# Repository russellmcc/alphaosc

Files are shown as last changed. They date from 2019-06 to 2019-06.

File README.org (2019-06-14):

* What is this?

This repository includes the design files and code for a eurorack-format digital audio oscillator.

* What's special about this digital oscillator?

Unlike other digital oscillators, this has very low aliasing.  This is achieved by running at a very high sampling rate (megahertz range, depending on target output pitch).

Also, many unusual waveforms, such as "comb" waveforms or "variable pulse saw" waveforms can be output.

The basic design and the output waveforms available are inspired closely (but not precisely) by Roland's Alpha Juno line of synthesizers.

* Project structure

The four-layer circuit board was designed using [[http://kicad-pcb.org][kicad]] and is available in the ~pcb~ subfolder.

Code for the arduino (which is reponsible for interfacing with the A/D converter for CV signals) is in the ~arduino~ folder.

Code for the fpga is written in [[https://clash-lang.org][clash]] and available in the ~src~ folder.

Panel design files are in the ~panel~ folder.

Scripts to design the tuning table are in the ~design~ folder.

This is the code for a digital oscillator core of a hardware synthesizer NCO developed in clash and arduino.  The oscillator is inspired by the Alpha Juno line of synthesizers by Roland.

* Tips for building/running

Note that this is a fairly advanced build and should be considered a "build at your own risk" type affair.

verilog code for the FPGA can be built by running the ~build.sh~ script in the ~src~ folder.  To program the FPGA, you'll need to use Lattice's tools available on [[http://www.latticesemi.com][their website]].  Note that you'll also need to include the ~lattice_alpha.lpf~ which locates the pins.

To run the test suite for the FPGA code, run ~test.sh~ in the ~src~ folder.

Note that some fuses on the arduino need to be set, specifically the "clock out" fuse.  This can be programmed with the following one-liner:

#+begin_src bash
avrdude -c avrispmkii -p m328p -U lfuse:w:0xB7:m
#+end_src

* License

Distributed under the terms of the GPLv3 (available in COPYING).  By contributing to this project, you agree to license your contribution under those terms.

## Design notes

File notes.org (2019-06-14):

* Assembly errors (not going to fix)
 - Saw lsb is stuck high due to pins 9 and 10 being bridged - this is due to a bogus pad so would be hard to fix.
 - Ditto saw bit 5 (near LSB) is stuck low due to crazy assembly error
 - So, switched saw (which actually needs all bits) with SUB (which doesn't).
* Stuff left to do [0/1]
 - [ ] PROJECT DOCUMENTATION!

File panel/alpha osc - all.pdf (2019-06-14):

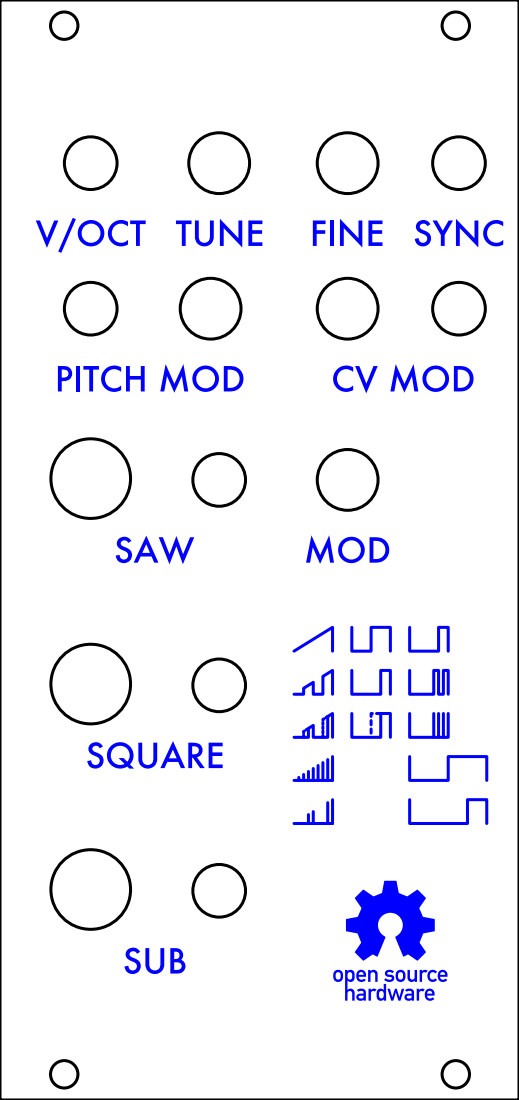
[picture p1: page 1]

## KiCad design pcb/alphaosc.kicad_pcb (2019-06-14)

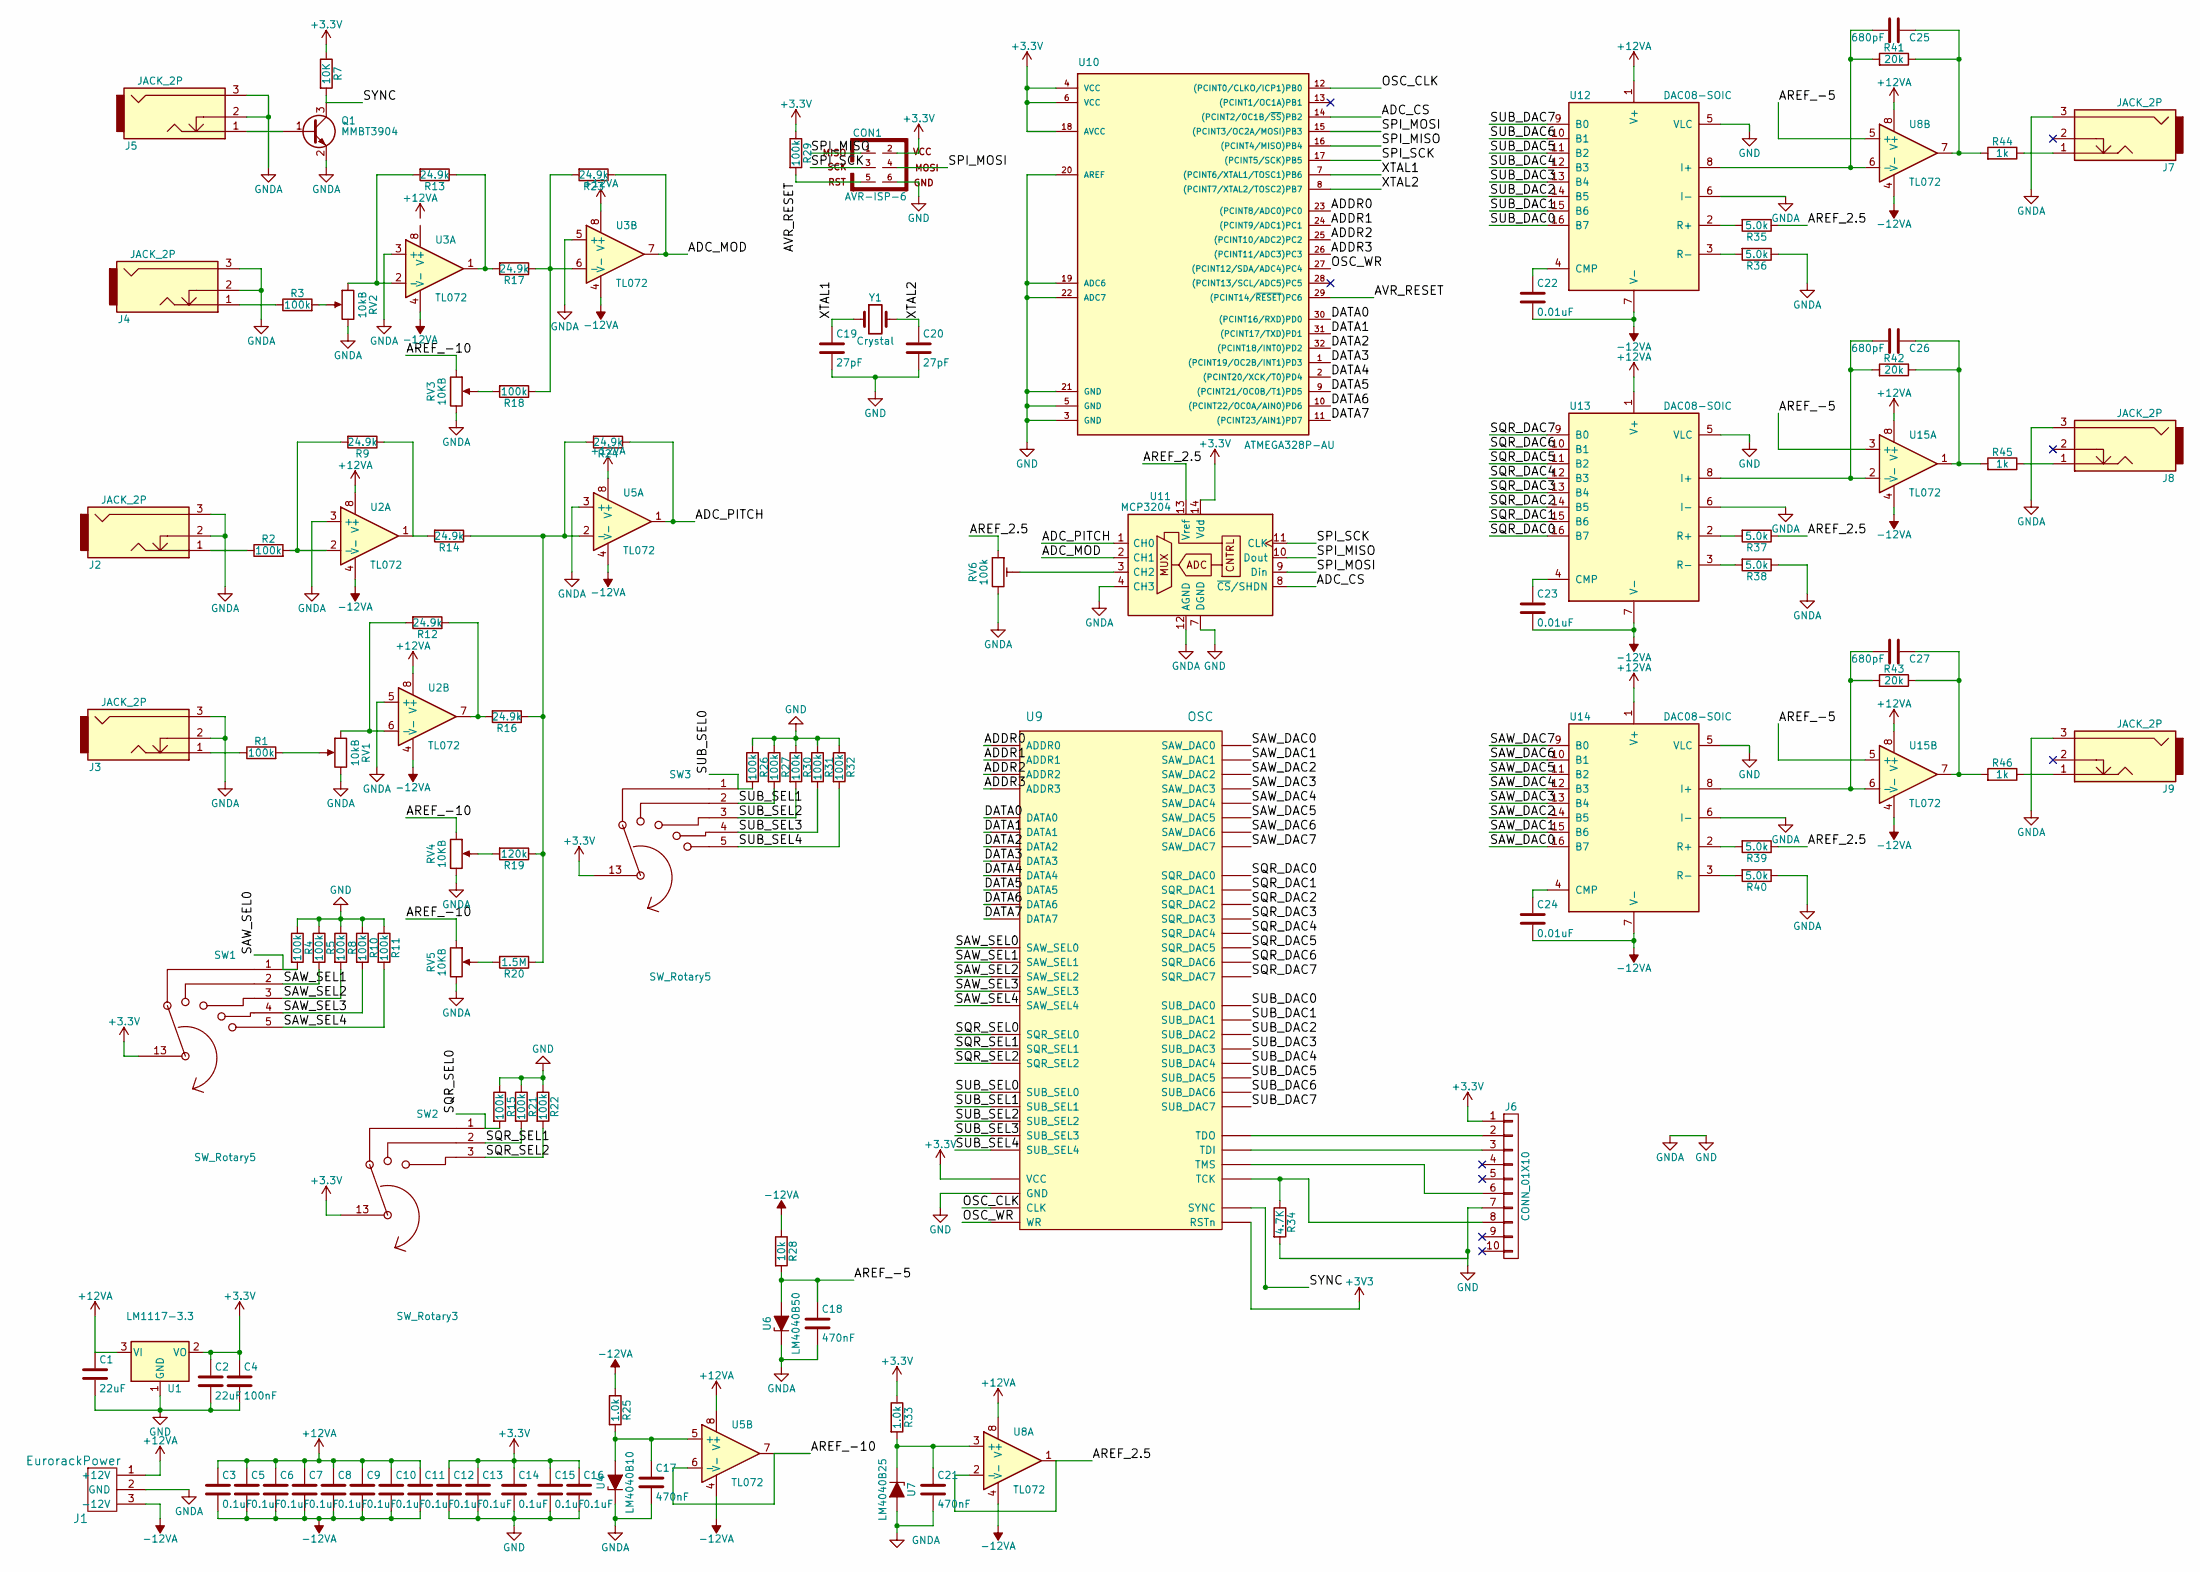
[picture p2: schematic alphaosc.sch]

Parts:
C1, C2: 22uF; C_0603
C3, C5, C6, C7, C8, C9, C10, C11, C12, C13, C14, C15, C16: 0.1uF; C_0603
C4: 100nF; C_0603
C17, C18, C21: 470nF; C_0603
C19, C20: 27pF; C_0603
C22, C23, C24: 0.01uF; C_0603
C25, C26, C27: 680pF; C_0603
CON1: AVR-ISP-6; Pin_Header_Straight_2x03_Pitch2.54mm
J1: EurorackPower; EurorackPower10
J2, J3, J4, J5, J7, J8, J9: JACK_2P; THONKICONN
J6: CONN_01X10; Pin_Header_Straight_1x10_Pitch2.54mm
Q1: MMBT3904; SOT-23
R1, R2, R3, R4, R5, R8, R10, R11, R15, R18, R21, R22, R26, R27, R29, R30, R31, R32: 100k; R_0603
R7: 10K; R_0603
R9, R12, R13, R14, R16, R17, R23, R24: 24.9k; R_0603
R19: 120k; R_0603
R20: 1.5M; R_0603
R25, R33: 1.0k; R_0603
R28: 10k; R_0603
R34: 4.7K; R_0603
R35, R36, R37, R38, R39, R40: 5.0k; R_0603
R41, R42, R43: 20k; R_0603
R44, R45, R46: 1k; R_0603
RV1, RV2: 10kB; Potentiometer_Bourns_PTV09A-1_Horizontal
RV3, RV4, RV5: 10KB; Potentiometer_Bourns_PTV09A-1_Horizontal
RV6: 100k; Potentiometer_Trimmer_Vishay_T73YP_Horizontal
SW1, SW3: SW_Rotary5; Alps_SRBV
SW2: SW_Rotary3; Alps_SRBV
U1: LM1117-3.3; SOT-223
U2, U3, U5, U8, U15: TL072; SOIC-8_3.9x4.9mm_Pitch1.27mm
U4: LM4040B10; SOT-23
U6: LM4040B50; SOT-23
U7: LM4040B25; SOT-23
U9: OSC; LAMXO256C-3TN100E
U10: ATMEGA328P-AU; TQFP-32_7x7mm_Pitch0.8mm
U11: MCP3204; SOIC-14_3.9x8.7mm_Pitch1.27mm
U12, U13, U14: DAC08-SOIC; SOIC-16_3.9x9.9mm_Pitch1.27mm
Y1: Crystal; Crystal_SMD_HC49-SD

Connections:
+12VA: C1.1, C3.1, C5.1, C6.1, C7.1, C8.1, C9.1, C10.1, C11.1, J1.1 (+12V), U1.3 (VI), U2.8 (V+), U3.8 (V+), U5.8 (V+), U8.8 (V+), U12.1 (V+), U13.1 (V+), U14.1 (V+), U15.8 (V+)
-12VA: C3.2, C5.2, C6.2, C7.2, C8.2, C9.2, C10.2, C11.2, C22.2, C23.2, C24.2, J1.3 (-12V), R25.1, R28.1, U2.4 (V-), U3.4 (V-), U5.4 (V-), U8.4 (V-), U12.7 (V-), U13.7 (V-), U14.7 (V-), U15.4 (V-)
/ADC_CS: U10.14 ((PCINT2/OC1B/~SS~)PB2), U11.8 (~CS~/SHDN)
/ADC_MOD: R23.1, U3.7, U11.2 (CH1)
/ADC_PITCH: R24.1, U5.1, U11.1 (CH0)
/ADDR0: U9.67 (ADDR0), U10.23 ((PCINT8/ADC0)PC0)
/ADDR1: U9.65 (ADDR1), U10.24 ((PCINT9/ADC1)PC1)
/ADDR2: U9.63 (ADDR2), U10.25 ((PCINT10/ADC2)PC2)
/ADDR3: U9.64 (ADDR3), U10.26 ((PCINT11/ADC3)PC3)
/AREF_2.5: R35.1, R37.1, R39.1, RV6.1, U8.1, U8.2 (-), U11.13 (Vref)
/AREF_-5: C18.1, R28.2, U6.2 (A), U8.5 (+), U15.3 (+), U15.5 (+)
/AREF_-10: RV3.1, RV4.1, RV5.1, U5.6 (-), U5.7
/AVR_RESET: CON1.5, R29.2, U10.29 ((PCINT14/~RESET~)PC6)
/DATA0: U9.70 (DATA0), U10.30 ((PCINT16/RXD)PD0)
/DATA1: U9.69 (DATA1), U10.31 ((PCINT17/TXD)PD1)
/DATA2: U9.16 (DATA2), U10.32 ((PCINT18/INT0)PD2)
/DATA3: U9.72 (DATA3), U10.1 ((PCINT19/OC2B/INT1)PD3)
/DATA4: U9.71 (DATA4), U10.2 ((PCINT20/XCK/T0)PD4)
/DATA5: U9.83 (DATA5), U10.9 ((PCINT21/OC0B/T1)PD5)
/DATA6: U9.76 (DATA6), U10.10 ((PCINT22/OC0A/AIN0)PD6)
/DATA7: U9.68 (DATA7), U10.11 ((PCINT23/AIN1)PD7)
/OSC_CLK: U9.36 (CLK), U10.12 ((PCINT0/CLKO/ICP1)PB0)
/OSC_WR: U9.66 (WR), U10.27 ((PCINT12/SDA/ADC4)PC4)
/SAW_DAC0: U9.9 (SAW_DAC0), U14.16 (B7)
/SAW_DAC1: U9.13 (SAW_DAC1), U14.15 (B6)
/SAW_DAC2: U9.59 (SAW_DAC2), U14.14 (B5)
/SAW_DAC3: U9.14 (SAW_DAC3), U14.13 (B4)
/SAW_DAC4: U9.61 (SAW_DAC4), U14.12 (B3)
/SAW_DAC5: U9.58 (SAW_DAC5), U14.11 (B2)
/SAW_DAC6: U9.47 (SAW_DAC6), U14.10 (B1)
/SAW_DAC7: U9.11 (SAW_DAC7), U14.9 (B0)
/SAW_SEL0: R4.2, SW1.1, U9.55 (SAW_SEL0)
/SAW_SEL1: R5.2, SW1.2, U9.56 (SAW_SEL1)
/SAW_SEL2: R8.2, SW1.3, U9.54 (SAW_SEL2)
/SAW_SEL3: R10.2, SW1.4, U9.57 (SAW_SEL3)
/SAW_SEL4: R11.2, SW1.5, U9.19 (SAW_SEL4)
/SPI_MISO: CON1.1, U10.16 ((PCINT4/MISO)PB4), U11.10 (Dout)
/SPI_MOSI: CON1.4, U10.15 ((PCINT3/OC2A/MOSI)PB3), U11.9 (Din)
/SPI_SCK: CON1.3, U10.17 ((PCINT5/SCK)PB5), U11.11 (CLK)
/SQR_DAC0: U9.96 (SQR_DAC0), U13.16 (B7)
/SQR_DAC1: U9.86 (SQR_DAC1), U13.15 (B6)
/SQR_DAC2: U9.80 (SQR_DAC2), U13.14 (B5)
/SQR_DAC3: U9.95 (SQR_DAC3), U13.13 (B4)
/SQR_DAC4: U9.100 (SQR_DAC4), U13.12 (B3)
/SQR_DAC5: U9.87 (SQR_DAC5), U13.11 (B2)
/SQR_DAC6: U9.82 (SQR_DAC6), U13.10 (B1)
/SQR_DAC7: U9.85 (SQR_DAC7), U13.9 (B0)
/SQR_SEL0: R15.2, SW2.1, U9.79 (SQR_SEL0)
/SQR_SEL1: R21.2, SW2.2, U9.73 (SQR_SEL1)
/SQR_SEL2: R22.2, SW2.3, U9.77 (SQR_SEL2)
/SUB_DAC0: U9.39 (SUB_DAC0), U12.16 (B7)
/SUB_DAC1: U9.34 (SUB_DAC1), U12.15 (B6)
/SUB_DAC2: U9.32 (SUB_DAC2), U12.14 (B5)
/SUB_DAC3: U9.38 (SUB_DAC3), U12.13 (B4)
/SUB_DAC4: U9.29 (SUB_DAC4), U12.12 (B3)
/SUB_DAC5: U9.37 (SUB_DAC5), U12.11 (B2)
/SUB_DAC6: U9.30 (SUB_DAC6), U12.10 (B1)
/SUB_DAC7: U9.53 (SUB_DAC7), U12.9 (B0)
/SUB_SEL0: R26.2, SW3.1, U9.45 (SUB_SEL0)
/SUB_SEL1: R27.2, SW3.2, U9.46 (SUB_SEL1)
/SUB_SEL2: R30.2, SW3.3, U9.43 (SUB_SEL2)
/SUB_SEL3: R31.2, SW3.4, U9.44 (SUB_SEL3)
/SUB_SEL4: R32.2, SW3.5, U9.50 (SUB_SEL4)
/SYNC: Q1.3 (C), R7.2, U9.78 (SYNC)
/XTAL1: C19.1, U10.7 ((PCINT6/XTAL1/TOSC1)PB6), Y1.1
/XTAL2: C20.1, U10.8 ((PCINT7/XTAL2/TOSC2)PB7), Y1.2
GND: C1.2, C2.2, C4.2, C12.2, C13.2, C14.2, C15.2, C16.2, C17.2, C18.2, C19.2, C20.2, C21.2, CON1.6, J1.2 (GND), J2.2, J2.3, J3.2, J3.3, J4.2, J4.3, J5.2, J5.3, J6.7, J7.3, J8.3, J9.3, Q1.2 (E), R4.1, R5.1, R8.1, R10.1, R11.1, R15.1, R21.1, R22.1, R26.1, R27.1, R30.1, R31.1, R32.1, R34.2, R36.1, R38.1, R40.1, RV1.3, RV2.3, RV3.3, RV4.3, RV5.3, RV6.3, U1.1 (GND), U2.3 (+), U2.5 (+), U3.3 (+), U3.5 (+), U4.1 (K), U5.3 (+), U6.1 (K), U7.2 (A), U9.12 (GND), U9.25 (GND), U9.40 (GND), U9.42 (GND), U9.62 (GND), U9.75 (GND), U9.84 (GND), U9.93 (GND), U10.3 (GND), U10.5 (GND), U10.19 (ADC6), U10.20 (AREF), U10.21 (GND), U10.22 (ADC7), U11.4 (CH3), U11.7 (DGND), U11.12 (AGND), U12.5 (VLC), U12.6 (I-), U13.5 (VLC), U13.6 (I-), U14.5 (VLC), U14.6 (I-)
unnamed: C17.1, R25.2, U4.2 (A), U5.5 (+)
unnamed: C21.1, R33.2, U7.1 (K), U8.3 (+)
unnamed: C22.1, U12.4 (CMP)
unnamed: C23.1, U13.4 (CMP)
unnamed: C24.1, U14.4 (CMP)
unnamed: C25.1, R41.1, R44.2, U8.7
unnamed: C25.2, R41.2, U8.6 (-), U12.8 (I+)
unnamed: C26.1, R42.1, R45.2, U15.1
unnamed: C26.2, R42.2, U13.8 (I+), U15.2 (-)
unnamed: C27.1, R43.1, R46.2, U15.7
unnamed: C27.2, R43.2, U14.8 (I+), U15.6 (-)
unnamed: J2.1, R2.1
unnamed: J3.1, R1.1
unnamed: J4.1, R3.1
unnamed: J5.1, Q1.1 (B)
unnamed: J6.2, U9.31 (TDO)
unnamed: J6.3, U9.33 (TDI)
unnamed: J6.6, U9.26 (TMS)
unnamed: J6.8, R34.1, U9.28 (TCK)
unnamed: J7.1, R44.1
unnamed: J8.1, R45.1
unnamed: J9.1, R46.1
unnamed: R1.2, RV1.2
unnamed: R2.2, R9.2, U2.2 (-)
unnamed: R3.2, RV2.2
unnamed: R12.1, R16.2, U2.7
unnamed: R12.2, RV1.1, U2.6 (-)
unnamed: R13.1, R17.2, U3.1
unnamed: R13.2, RV2.1, U3.2 (-)
unnamed: R14.1, R16.1, R19.1, R20.1, R24.2, U5.2 (-)
unnamed: R9.1, R14.2, U2.1
unnamed: R17.1, R18.1, R23.2, U3.6 (-)
unnamed: R18.2, RV3.2
unnamed: R19.2, RV4.2
unnamed: R20.2, RV5.2
unnamed: R35.2, U12.2 (R+)
unnamed: R36.2, U12.3 (R-)
unnamed: R37.2, U13.2 (R+)
unnamed: R38.2, U13.3 (R-)
unnamed: R39.2, U14.2 (R+)
unnamed: R40.2, U14.3 (R-)
unnamed: RV6.2, U11.3 (CH2)

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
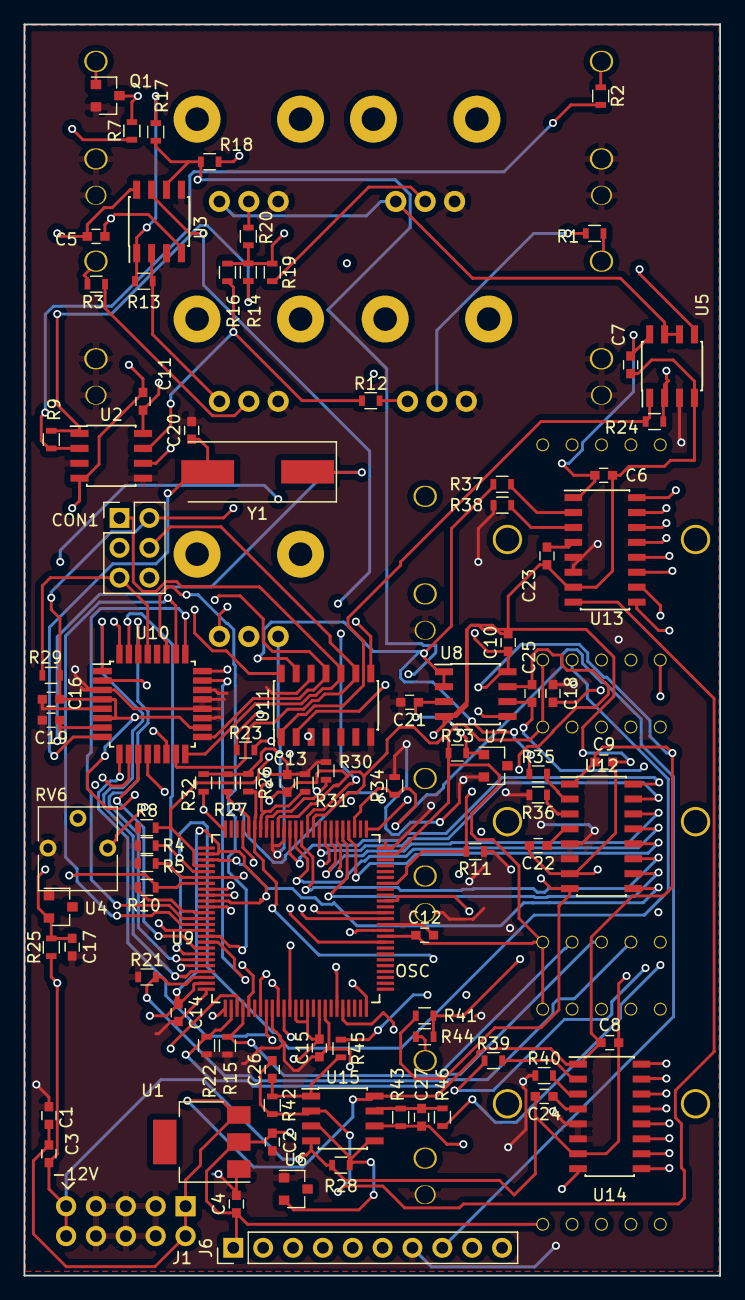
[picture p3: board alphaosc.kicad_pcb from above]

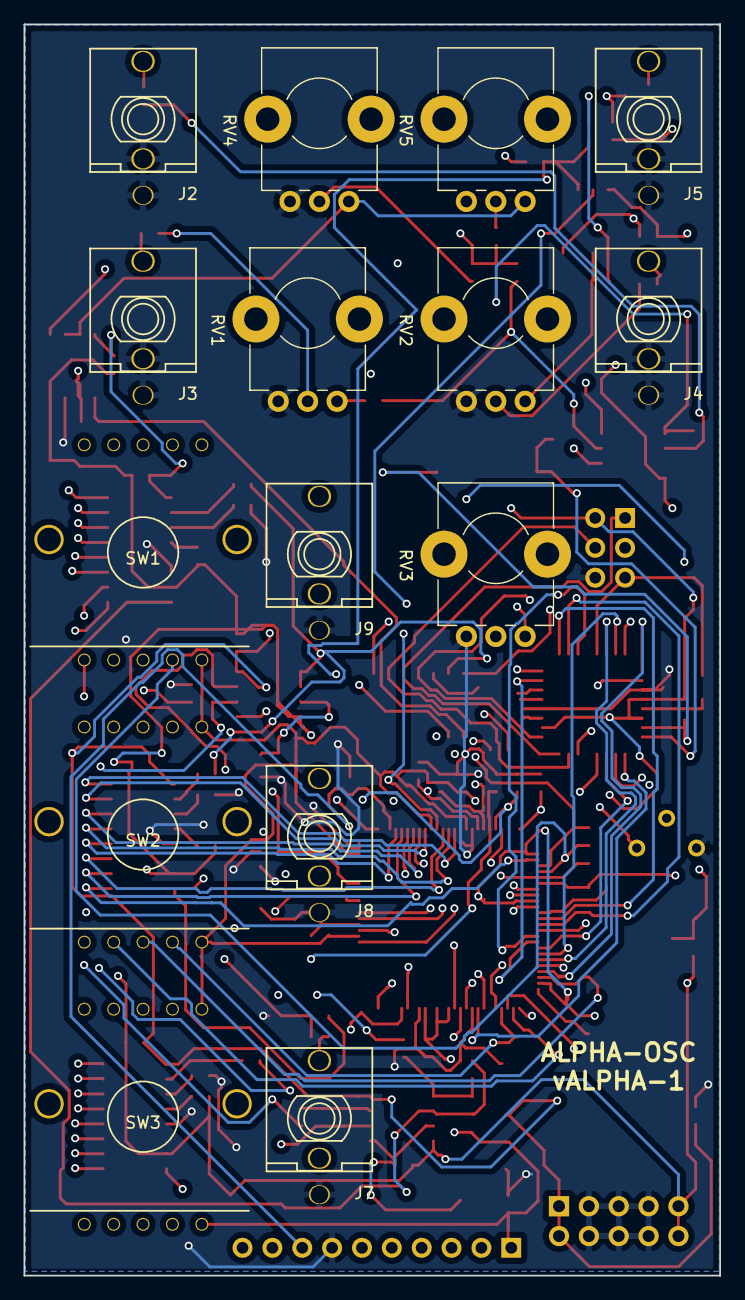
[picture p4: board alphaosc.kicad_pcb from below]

Board: 4 copper layers, 59.2 x 106.4 mm, 108 parts (15 on the bottom side), 110 nets.

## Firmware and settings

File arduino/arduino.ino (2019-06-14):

// THIS ADJUSTS TUNING
const float maxVolts = 10.1f;
const float alphaFloat = 0.99;  // CHANGE THIS TO ADD PORTAMENTO/TUNING STABILITY.
                             // higher the value, more portamento and more stability.


const uint16_t PITCH_LOOKUP_TABLE[4096] PROGMEM = {2048,2048,2049,2049,2049,2050,2050,2050,2051,2051,2051,2052,2052,2053,2053,2053,2054,2054,2054,2055,2055,2055,2056,2056,2056,2057,2057,2057,2058,2058,2058,2059,2059,2059,2060,2060,2061,2061,2061,2062,2062,2062,2063,2063,2063,2064,2064,2064,2065,2065,2065,2066,2066,2066,2067,2067,2068,2068,2068,2069,2069,2069,2070,2070,2070,2071,2071,2071,2072,2072,2072,2073,2073,2073,2074,2074,2075,2075,2075,2076,2076,2076,2077,2077,2077,2078,2078,2078,2079,2079,2079,2080,2080,2080,2081,2081,2082,2082,2082,2083,2083,2083,2084,2084,2084,2085,2085,2085,2086,2086,2086,2087,2087,2088,2088,2088,2089,2089,2089,2090,2090,2090,2091,2091,2091,2092,2092,2092,2093,2093,2094,2094,2094,2095,2095,2095,2096,2096,2096,2097,2097,2097,2098,2098,2099,2099,2099,2100,2100,2100,2101,2101,2101,2102,2102,2102,2103,2103,2103,2104,2104,2105,2105,2105,2106,2106,2106,2107,2107,2107,2108,2108,2108,2109,2109,2110,2110,2110,2111,2111,2111,2112,2112,2112,2113,2113,2113,2114,2114,2115,2115,2115,2116,2116,2116,2117,2117,2117,2118,2118,2119,2119,2119,2120,2120,2120,2121,2121,2121,2122,2122,2122,2123,2123,2124,2124,2124,2125,2125,2125,2126,2126,2126,2127,2127,2127,2128,2128,2129,2129,2129,2130,2130,2130,2131,2131,2131,2132,2132,2133,2133,2133,2134,2134,2134,2135,2135,2135,2136,2136,2137,2137,2137,2138,2138,2138,2139,2139,2139,2140,2140,2140,2141,2141,2142,2142,2142,2143,2143,2143,2144,2144,2144,2145,2145,2146,2146,2146,2147,2147,2147,2148,2148,2148,2149,2149,2150,2150,2150,2151,2151,2151,2152,2152,2152,2153,2153,2154,2154,2154,2155,2155,2155,2156,2156,2156,2157,2157,2158,2158,2158,2159,2159,2159,2160,2160,2160,2161,2161,2162,2162,2162,2163,2163,2163,2164,2164,2165,2165,2165,2166,2166,2166,2167,2167,2167,2168,2168,2169,2169,2169,2170,2170,2170,2171,2171,2171,2172,2172,2173,2173,2173,2174,2174,2174,2175,2175,2176,2176,2176,2177,2177,2177,2178,2178,2178,2179,2179,2180,2180,2180,2181,2181,2181,2182,2182,2183,2183,2183,2184,2184,2184,2185,2185,2186,2186,2186,2187,2187,2187,2188,2188,2188,2189,2189,2190,2190,2190,2191,2191,2191,2192,2192,2193,2193,2193,2194,2194,2194,2195,2195,2196,2196,2196,2197,2197,2197,2198,2198,2198,2199,2199,2200,2200,2200,2201,2201,2201,2202,2202,2203,2203,2203,2204,2204,2204,2205,2205,2206,2206,2206,2207,2207,2207,2208,2208,2209,2209,2209,2210,2210,2210,2211,2211,2212,2212,2212,2213,2213,2213,2214,2214,2215,2215,2215,2216,2216,2216,2217,2217,2218,2218,2218,2219,2219,2219,2220,2220,2221,2221,2221,2222,2222,2222,2223,2223,2224,2224,2224,2225,2225,2225,2226,2226,2227,2227,2227,2228,2228,2228,2229,2229,2230,2230,2230,2231,2231,2231,2232,2232,2233,2233,2233,2234,2234,2234,2235,2235,2236,2236,2236,2237,2237,2238,2238,2238,2239,2239,2239,2240,2240,2241,2241,2241,2242,2242,2242,2243,2243,2244,2244,2244,2245,2245,2245,2246,2246,2247,2247,2247,2248,2248,2249,2249,2249,2250,2250,2250,2251,2251,2252,2252,2252,2253,2253,2253,2254,2254,2255,2255,2255,2256,2256,2257,2257,2257,2258,2258,2258,2259,2259,2260,2260,2260,2261,2261,2262,2262,2262,2263,2263,2263,2264,2264,2265,2265,2265,2266,2266,2266,2267,2267,2268,2268,2268,2269,2269,2270,2270,2270,2271,2271,2271,2272,2272,2273,2273,2273,2274,2274,2275,2275,2275,2276,2276,2276,2277,2277,2278,2278,2278,2279,2279,2280,2280,2280,2281,2281,2281,2282,2282,2283,2283,2283,2284,2284,2285,2285,2285,2286,2286,2287,2287,2287,2288,2288,2288,2289,2289,2290,2290,2290,2291,2291,2292,2292,2292,2293,2293,2293,2294,2294,2295,2295,2295,2296,2296,2297,2297,2297,2298,2298,2299,2299,2299,2300,2300,2300,2301,2301,2302,2302,2302,2303,2303,2304,2304,2304,2305,2305,2306,2306,2306,2307,2307,2308,2308,2308,2309,2309,2309,2310,2310,2311,2311,2311,2312,2312,2313,2313,2313,2314,2314,2315,2315,2315,2316,2316,2317,2317,2317,2318,2318,2318,2319,2319,2320,2320,2320,2321,2321,2322,2322,2322,2323,2323,2324,2324,2324,2325,2325,2326,2326,2326,2327,2327,2328,2328,2328,2329,2329,2329,2330,2330,2331,2331,2331,2332,2332,2333,2333,2333,2334,2334,2335,2335,2335,2336,2336,2337,2337,2337,2338,2338,2339,2339,2339,2340,2340,2341,2341,2341,2342,2342,2343,2343,2343,2344,2344,2345,2345,2345,2346,2346,2346,2347,2347,2348,2348,2348,2349,2349,2350,2350,2350,2351,2351,2352,2352,2352,2353,2353,2354,2354,2354,2355,2355,2356,2356,2356,2357,2357,2358,2358,2358,2359,2359,2360,2360,2360,2361,2361,2362,2362,2362,2363,2363,2364,2364,2364,2365,2365,2366,2366,2366,2367,2367,2368,2368,2368,2369,2369,2370,2370,2370,2371,2371,2372,2372,2372,2373,2373,2374,2374,2374,2375,2375,2376,2376,2376,2377,2377,2378,2378,2378,2379,2379,2380,2380,2380,2381,2381,2382,2382,2383,2383,2383,2384,2384,2385,2385,2385,2386,2386,2387,2387,2387,2388,2388,2389,2389,2389,2390,2390,2391,2391,2391,2392,2392,2393,2393,2393,2394,2394,2395,2395,2395,2396,2396,2397,2397,2397,2398,2398,2399,2399,2399,2400,2400,2401,2401,2402,2402,2402,2403,2403,2404,2404,2404,2405,2405,2406,2406,2406,2407,2407,2408,2408,2408,2409,2409,2410,2410,2410,2411,2411,2412,2412,2413,2413,2413,2414,2414,2415,2415,2415,2416,2416,2417,2417,2417,2418,2418,2419,2419,2419,2420,2420,2421,2421,2422,2422,2422,2423,2423,2424,2424,2424,2425,2425,2426,2426,2426,2427,2427,2428,2428,2428,2429,2429,2430,2430,2431,2431,2431,2432,2432,2433,2433,2433,2434,2434,2435,2435,2435,2436,2436,2437,2437,2438,2438,2438,2439,2439,2440,2440,2440,2441,2441,2442,2442,2443,2443,2443,2444,2444,2445,2445,2445,2446,2446,2447,2447,2447,2448,2448,2449,2449,2450,2450,2450,2451,2451,2452,2452,2452,2453,2453,2454,2454,2455,2455,2455,2456,2456,2457,2457,2457,2458,2458,2459,2459,2460,2460,2460,2461,2461,2462,2462,2462,2463,2463,2464,2464,2465,2465,2465,2466,2466,2467,2467,2467,2468,2468,2469,2469,2470,2470,2470,2471,2471,2472,2472,2472,2473,2473,2474,2474,2475,2475,2475,2476,2476,2477,2477,2477,2478,2478,2479,2479,2480,2480,2480,2481,2481,2482,2482,2483,2483,2483,2484,2484,2485,2485,2485,2486,2486,2487,2487,2488,2488,2488,2489,2489,2490,2490,2491,2491,2491,2492,2492,2493,2493,2493,2494,2494,2495,2495,2496,2496,2496,2497,2497,2498,2498,2499,2499,2499,2500,2500,2501,2501,2501,2502,2502,2503,2503,2504,2504,2504,2505,2505,2506,2506,2507,2507,2507,2508,2508,2509,2509,2510,2510,2510,2511,2511,2512,2512,2513,2513,2513,2514,2514,2515,2515,2516,2516,2516,2517,2517,2518,2518,2518,2519,2519,2520,2520,2521,2521,2521,2522,2522,2523,2523,2524,2524,2524,2525,2525,2526,2526,2527,2527,2527,2528,2528,2529,2529,2530,2530,2530,2531,2531,2532,2532,2533,2533,2533,2534,2534,2535,2535,2536,2536,2536,2537,2537,2538,2538,2539,2539,2539,2540,2540,2541,2541,2542,2542,2542,2543,2543,2544,2544,2545,2545,2545,2546,2546,2547,2547,2548,2548,2548,2549,2549,2550,2550,2551,2551,2552,2552,2552,2553,2553,2554,2554,2555,2555,2555,2556,2556,2557,2557,2558,2558,2558,2559,2559,2560,2560,2561,2561,2561,2562,2562,2563,2563,2564,2564,2565,2565,2565,2566,2566,2567,2567,2568,2568,2568,2569,2569,2570,2570,2571,2571,2571,2572,2572,2573,2573,2574,2574,2575,2575,2575,2576,2576,2577,2577,2578,2578,2578,2579,2579,2580,2580,2581,2581,2581,2582,2582,2583,2583,2584,2584,2585,2585,2585,2586,2586,2587,2587,2588,2588,2588,2589,2589,2590,2590,2591,2591,2592,2592,2592,2593,2593,2594,2594,2595,2595,2596,2596,2596,2597,2597,2598,2598,2599,2599,2599,2600,2600,2601,2601,2602,2602,2603,2603,2603,2604,2604,2605,2605,2606,2606,2607,2607,2607,2608,2608,2609,2609,2610,2610,2610,2611,2611,2612,2612,2613,2613,2614,2614,2614,2615,2615,2616,2616,2617,2617,2618,2618,2618,2619,2619,2620,2620,2621,2621,2622,2622,2622,2623,2623,2624,2624,2625,2625,2626,2626,2626,2627,2627,2628,2628,2629,2629,2630,2630,2630,2631,2631,2632,2632,2633,2633,2634,2634,2634,2635,2635,2636,2636,2637,2637,2638,2638,2638,2639,2639,2640,2640,2641,2641,2642,2642,2642,2643,2643,2644,2644,2645,2645,2646,2646,2647,2647,2647,2648,2648,2649,2649,2650,2650,2651,2651,2651,2652,2652,2653,2653,2654,2654,2655,2655,2655,2656,2656,2657,2657,2658,2658,2659,2659,2660,2660,2660,2661,2661,2662,2662,2663,2663,2664,2664,2664,2665,2665,2666,2666,2667,2667,2668,2668,2669,2669,2669,2670,2670,2671,2671,2672,2672,2673,2673,2674,2674,2674,2675,2675,2676,2676,2677,2677,2678,2678,2678,2679,2679,2680,2680,2681,2681,2682,2682,2683,2683,2683,2684,2684,2685,2685,2686,2686,2687,2687,2688,2688,2688,2689,2689,2690,2690,2691,2691,2692,2692,2693,2693,2693,2694,2694,2695,2695,2696,2696,2697,2697,2698,2698,2699,2699,2699,2700,2700,2701,2701,2702,2702,2703,2703,2704,2704,2704,2705,2705,2706,2706,2707,2707,2708,2708,2709,2709,2709,2710,2710,2711,2711,2712,2712,2713,2713,2714,2714,2715,2715,2715,2716,2716,2717,2717,2718,2718,2719,2719,2720,2720,2721,2721,2721,2722,2722,2723,2723,2724,2724,2725,2725,2726,2726,2727,2727,2727,2728,2728,2729,2729,2730,2730,2731,2731,2732,2732,2733,2733,2733,2734,2734,2735,2735,2736,2736,2737,2737,2738,2738,2739,2739,2739,2740,2740,2741,2741,2742,2742,2743,2743,2744,2744,2745,2745,2745,2746,2746,2747,2747,2748,2748,2749,2749,2750,2750,2751,2751,2752,2752,2752,2753,2753,2754,2754,2755,2755,2756,2756,2757,2757,2758,2758,2759,2759,2759,2760,2760,2761,2761,2762,2762,2763,2763,2764,2764,2765,2765,2766,2766,2766,2767,2767,2768,2768,2769,2769,2770,2770,2771,2771,2772,2772,2773,2773,2774,2774,2774,2775,2775,2776,2776,2777,2777,2778,2778,2779,2779,2780,2780,2781,2781,2782,2782,2782,2783,2783,2784,2784,2785,2785,2786,2786,2787,2787,2788,2788,2789,2789,2790,2790,2790,2791,2791,2792,2792,2793,2793,2794,2794,2795,2795,2796,2796,2797,2797,2798,2798,2799,2799,2799,2800,2800,2801,2801,2802,2802,2803,2803,2804,2804,2805,2805,2806,2806,2807,2807,2808,2808,2808,2809,2809,2810,2810,2811,2811,2812,2812,2813,2813,2814,2814,2815,2815,2816,2816,2817,2817,2818,2818,2818,2819,2819,2820,2820,2821,2821,2822,2822,2823,2823,2824,2824,2825,2825,2826,2826,2827,2827,2828,2828,2828,2829,2829,2830,2830,2831,2831,2832,2832,2833,2833,2834,2834,2835,2835,2836,2836,2837,2837,2838,2838,2839,2839,2840,2840,2840,2841,2841,2842,2842,2843,2843,2844,2844,2845,2845,2846,2846,2847,2847,2848,2848,2849,2849,2850,2850,2851,2851,2852,2852,2853,2853,2853,2854,2854,2855,2855,2856,2856,2857,2857,2858,2858,2859,2859,2860,2860,2861,2861,2862,2862,2863,2863,2864,2864,2865,2865,2866,2866,2867,2867,2868,2868,2869,2869,2869,2870,2870,2871,2871,2872,2872,2873,2873,2874,2874,2875,2875,2876,2876,2877,2877,2878,2878,2879,2879,2880,2880,2881,2881,2882,2882,2883,2883,2884,2884,2885,2885,2886,2886,2887,2887,2888,2888,2888,2889,2889,2890,2890,2891,2891,2892,2892,2893,2893,2894,2894,2895,2895,2896,2896,2897,2897,2898,2898,2899,2899,2900,2900,2901,2901,2902,2902,2903,2903,2904,2904,2905,2905,2906,2906,2907,2907,2908,2908,2909,2909,2910,2910,2911,2911,2912,2912,2913,2913,2914,2914,2915,2915,2915,2916,2916,2917,2917,2918,2918,2919,2919,2920,2920,2921,2921,2922,2922,2923,2923,2924,2924,2925,2925,2926,2926,2927,2927,2928,2928,2929,2929,2930,2930,2931,2931,2932,2932,2933,2933,2934,2934,2935,2935,2936,2936,2937,2937,2938,2938,2939,2939,2940,2940,2941,2941,2942,2942,2943,2943,2944,2944,2945,2945,2946,2946,2947,2947,2948,2948,2949,2949,2950,2950,2951,2951,2952,2952,2953,2953,2954,2954,2955,2955,2956,2956,2957,2957,2958,2958,2959,2959,2960,2960,2961,2961,2962,2962,2963,2963,2964,2964,2965,2965,2966,2966,2967,2967,2968,2968,2969,2969,2970,2970,2971,2971,2972,2972,2973,2973,2974,2974,2975,2975,2976,2976,2977,2977,2978,2978,2979,2979,2980,2980,2981,2981,2982,2982,2983,2983,2984,2984,2985,2985,2986,2986,2987,2987,2988,2988,2989,2989,2990,2990,2991,2991,2992,2992,2993,2993,2994,2994,2995,2996,2996,2997,2997,2998,2998,2999,2999,3000,3000,3001,3001,3002,3002,3003,3003,3004,3004,3005,3005,3006,3006,3007,3007,3008,3008,3009,3009,3010,3010,3011,3011,3012,3012,3013,3013,3014,3014,3015,3015,3016,3016,3017,3017,3018,3018,3019,3019,3020,3020,3021,3021,3022,3022,3023,3024,3024,3025,3025,3026,3026,3027,3027,3028,3028,3029,3029,3030,3030,3031,3031,3032,3032,3033,3033,3034,3034,3035,3035,3036,3036,3037,3037,3038,3038,3039,3039,3040,3040,3041,3041,3042,3043,3043,3044,3044,3045,3045,3046,3046,3047,3047,3048,3048,3049,3049,3050,3050,3051,3051,3052,3052,3053,3053,3054,3054,3055,3055,3056,3056,3057,3057,3058,3059,3059,3060,3060,3061,3061,3062,3062,3063,3063,3064,3064,3065,3065,3066,3066,3067,3067,3068,3068,3069,3069,3070,3070,3071,3071,3072,3073,3073,3074,3074,3075,3075,3076,3076,3077,3077,3078,3078,3079,3079,3080,3080,3081,3081,3082,3082,3083,3083,3084,3084,3085,3086,3086,3087,3087,3088,3088,3089,3089,3090,3090,3091,3091,3092,3092,3093,3093,3094,3094,3095,3095,3096,3097,3097,3098,3098,3099,3099,3100,3100,3101,3101,3102,3102,3103,3103,3104,3104,3105,3105,3106,3106,3107,3108,3108,3109,3109,3110,3110,3111,3111,3112,3112,3113,3113,3114,3114,3115,3115,3116,3117,3117,3118,3118,3119,3119,3120,3120,3121,3121,3122,3122,3123,3123,3124,3124,3125,3125,3126,3127,3127,3128,3128,3129,3129,3130,3130,3131,3131,3132,3132,3133,3133,3134,3134,3135,3136,3136,3137,3137,3138,3138,3139,3139,3140,3140,3141,3141,3142,3142,3143,3144,3144,3145,3145,3146,3146,3147,3147,3148,3148,3149,3149,3150,3150,3151,3152,3152,3153,3153,3154,3154,3155,3155,3156,3156,3157,3157,3158,3158,3159,3160,3160,3161,3161,3162,3162,3163,3163,3164,3164,3165,3165,3166,3166,3167,3168,3168,3169,3169,3170,3170,3171,3171,3172,3172,3173,3173,3174,3175,3175,3176,3176,3177,3177,3178,3178,3179,3179,3180,3180,3181,3182,3182,3183,3183,3184,3184,3185,3185,3186,3186,3187,3187,3188,3189,3189,3190,3190,3191,3191,3192,3192,3193,3193,3194,3194,3195,3196,3196,3197,3197,3198,3198,3199,3199,3200,3200,3201,3201,3202,3203,3203,3204,3204,3205,3205,3206,3206,3207,3207,3208,3209,3209,3210,3210,3211,3211,3212,3212,3213,3213,3214,3215,3215,3216,3216,3217,3217,3218,3218,3219,3219,3220,3221,3221,3222,3222,3223,3223,3224,3224,3225,3225,3226,3227,3227,3228,3228,3229,3229,3230,3230,3231,3231,3232,3233,3233,3234,3234,3235,3235,3236,3236,3237,3237,3238,3239,3239,3240,3240,3241,3241,3242,3242,3243,3243,3244,3245,3245,3246,3246,3247,3247,3248,3248,3249,3250,3250,3251,3251,3252,3252,3253,3253,3254,3254,3255,3256,3256,3257,3257,3258,3258,3259,3259,3260,3261,3261,3262,3262,3263,3263,3264,3264,3265,3266,3266,3267,3267,3268,3268,3269,3269,3270,3270,3271,3272,3272,3273,3273,3274,3274,3275,3275,3276,3277,3277,3278,3278,3279,3279,3280,3280,3281,3282,3282,3283,3283,3284,3284,3285,3285,3286,3287,3287,3288,3288,3289,3289,3290,3290,3291,3292,3292,3293,3293,3294,3294,3295,3295,3296,3297,3297,3298,3298,3299,3299,3300,3301,3301,3302,3302,3303,3303,3304,3304,3305,3306,3306,3307,3307,3308,3308,3309,3309,3310,3311,3311,3312,3312,3313,3313,3314,3315,3315,3316,3316,3317,3317,3318,3318,3319,3320,3320,3321,3321,3322,3322,3323,3323,3324,3325,3325,3326,3326,3327,3327,3328,3329,3329,3330,3330,3331,3331,3332,3333,3333,3334,3334,3335,3335,3336,3336,3337,3338,3338,3339,3339,3340,3340,3341,3342,3342,3343,3343,3344,3344,3345,3346,3346,3347,3347,3348,3348,3349,3349,3350,3351,3351,3352,3352,3353,3353,3354,3355,3355,3356,3356,3357,3357,3358,3359,3359,3360,3360,3361,3361,3362,3363,3363,3364,3364,3365,3365,3366,3367,3367,3368,3368,3369,3369,3370,3371,3371,3372,3372,3373,3373,3374,3375,3375,3376,3376,3377,3377,3378,3379,3379,3380,3380,3381,3381,3382,3383,3383,3384,3384,3385,3385,3386,3387,3387,3388,3388,3389,3389,3390,3391,3391,3392,3392,3393,3393,3394,3395,3395,3396,3396,3397,3397,3398,3399,3399,3400,3400,3401,3401,3402,3403,3403,3404,3404,3405,3405,3406,3407,3407,3408,3408,3409,3410,3410,3411,3411,3412,3412,3413,3414,3414,3415,3415,3416,3416,3417,3418,3418,3419,3419,3420,3420,3421,3422,3422,3423,3423,3424,3425,3425,3426,3426,3427,3427,3428,3429,3429,3430,3430,3431,3432,3432,3433,3433,3434,3434,3435,3436,3436,3437,3437,3438,3438,3439,3440,3440,3441,3441,3442,3443,3443,3444,3444,3445,3445,3446,3447,3447,3448,3448,3449,3450,3450,3451,3451,3452,3452,3453,3454,3454,3455,3455,3456,3457,3457,3458,3458,3459,3459,3460,3461,3461,3462,3462,3463,3464,3464,3465,3465,3466,3467,3467,3468,3468,3469,3469,3470,3471,3471,3472,3472,3473,3474,3474,3475,3475,3476,3477,3477,3478,3478,3479,3479,3480,3481,3481,3482,3482,3483,3484,3484,3485,3485,3486,3487,3487,3488,3488,3489,3489,3490,3491,3491,3492,3492,3493,3494,3494,3495,3495,3496,3497,3497,3498,3498,3499,3500,3500,3501,3501,3502,3503,3503,3504,3504,3505,3505,3506,3507,3507,3508,3508,3509,3510,3510,3511,3511,3512,3513,3513,3514,3514,3515,3516,3516,3517,3517,3518,3519,3519,3520,3520,3521,3522,3522,3523,3523,3524,3525,3525,3526,3526,3527,3527,3528,3529,3529,3530,3530,3531,3532,3532,3533,3533,3534,3535,3535,3536,3536,3537,3538,3538,3539,3539,3540,3541,3541,3542,3542,3543,3544,3544,3545,3545,3546,3547,3547,3548,3548,3549,3550,3550,3551,3551,3552,3553,3553,3554,3554,3555,3556,3556,3557,3557,3558,3559,3559,3560,3560,3561,3562,3562,3563,3563,3564,3565,3565,3566,3566,3567,3568,3568,3569,3570,3570,3571,3571,3572,3573,3573,3574,3574,3575,3576,3576,3577,3577,3578,3579,3579,3580,3580,3581,3582,3582,3583,3583,3584,3585,3585,3586,3586,3587,3588,3588,3589,3590,3590,3591,3591,3592,3593,3593,3594,3594,3595,3596,3596,3597,3597,3598,3599,3599,3600,3600,3601,3602,3602,3603,3604,3604,3605,3605,3606,3607,3607,3608,3608,3609,3610,3610,3611,3611,3612,3613,3613,3614,3614,3615,3616,3616,3617,3618,3618,3619,3619,3620,3621,3621,3622,3622,3623,3624,3624,3625,3626,3626,3627,3627,3628,3629,3629,3630,3630,3631,3632,3632,3633,3634,3634,3635,3635,3636,3637,3637,3638,3638,3639,3640,3640,3641,3642,3642,3643,3643,3644,3645,3645,3646,3646,3647,3648,3648,3649,3650,3650,3651,3651,3652,3653,3653,3654,3654,3655,3656,3656,3657,3658,3658,3659,3659,3660,3661,3661,3662,3663,3663,3664,3664,3665,3666,3666,3667,3667,3668,3669,3669,3670,3671,3671,3672,3672,3673,3674,3674,3675,3676,3676,3677,3677,3678,3679,3679,3680,3681,3681,3682,3682,3683,3684,3684,3685,3686,3686,3687,3687,3688,3689,3689,3690,3691,3691,3692,3692,3693,3694,3694,3695,3696,3696,3697,3697,3698,3699,3699,3700,3701,3701,3702,3702,3703,3704,3704,3705,3706,3706,3707,3707,3708,3709,3709,3710,3711,3711,3712,3712,3713,3714,3714,3715,3716,3716,3717,3717,3718,3719,3719,3720,3721,3721,3722,3723,3723,3724,3724,3725,3726,3726,3727,3728,3728,3729,3729,3730,3731,3731,3732,3733,3733,3734,3734,3735,3736,3736,3737,3738,3738,3739,3740,3740,3741,3741,3742,3743,3743,3744,3745,3745,3746,3747,3747,3748,3748,3749,3750,3750,3751,3752,3752,3753,3754,3754,3755,3755,3756,3757,3757,3758,3759,3759,3760,3761,3761,3762,3762,3763,3764,3764,3765,3766,3766,3767,3768,3768,3769,3769,3770,3771,3771,3772,3773,3773,3774,3775,3775,3776,3776,3777,3778,3778,3779,3780,3780,3781,3782,3782,3783,3783,3784,3785,3785,3786,3787,3787,3788,3789,3789,3790,3791,3791,3792,3792,3793,3794,3794,3795,3796,3796,3797,3798,3798,3799,3800,3800,3801,3801,3802,3803,3803,3804,3805,3805,3806,3807,3807,3808,3809,3809,3810,3810,3811,3812,3812,3813,3814,3814,3815,3816,3816,3817,3818,3818,3819,3820,3820,3821,3821,3822,3823,3823,3824,3825,3825,3826,3827,3827,3828,3829,3829,3830,3831,3831,3832,3832,3833,3834,3834,3835,3836,3836,3837,3838,3838,3839,3840,3840,3841,3842,3842,3843,3843,3844,3845,3845,3846,3847,3847,3848,3849,3849,3850,3851,3851,3852,3853,3853,3854,3855,3855,3856,3857,3857,3858,3858,3859,3860,3860,3861,3862,3862,3863,3864,3864,3865,3866,3866,3867,3868,3868,3869,3870,3870,3871,3872,3872,3873,3874,3874,3875,3875,3876,3877,3877,3878,3879,3879,3880,3881,3881,3882,3883,3883,3884,3885,3885,3886,3887,3887,3888,3889,3889,3890,3891,3891,3892,3893,3893,3894,3895,3895,3896,3897,3897,3898,3899,3899,3900,3901,3901,3902,3902,3903,3904,3904,3905,3906,3906,3907,3908,3908,3909,3910,3910,3911,3912,3912,3913,3914,3914,3915,3916,3916,3917,3918,3918,3919,3920,3920,3921,3922,3922,3923,3924,3924,3925,3926,3926,3927,3928,3928,3929,3930,3930,3931,3932,3932,3933,3934,3934,3935,3936,3936,3937,3938,3938,3939,3940,3940,3941,3942,3942,3943,3944,3944,3945,3946,3946,3947,3948,3948,3949,3950,3950,3951,3952,3952,3953,3954,3954,3955,3956,3956,3957,3958,3958,3959,3960,3960,3961,3962,3962,3963,3964,3964,3965,3966,3966,3967,3968,3968,3969,3970,3970,3971,3972,3972,3973,3974,3974,3975,3976,3976,3977,3978,3978,3979,3980,3981,3981,3982,3983,3983,3984,3985,3985,3986,3987,3987,3988,3989,3989,3990,3991,3991,3992,3993,3993,3994,3995,3995,3996,3997,3997,3998,3999,3999,4000,4001,4001,4002,4003,4003,4004,4005,4006,4006,4007,4008,4008,4009,4010,4010,4011,4012,4012,4013,4014,4014,4015,4016,4016,4017,4018,4018,4019,4020,4020,4021,4022,4023,4023,4024,4025,4025,4026,4027,4027,4028,4029,4029,4030,4031,4031,4032,4033,4033,4034,4035,4035,4036,4037,4038,4038,4039,4040,4040,4041,4042,4042,4043,4044,4044,4045,4046,4046,4047,4048,4048,4049,4050,4051,4051,4052,4053,4053,4054,4055,4055,4056,4057,4057,4058,4059,4059,4060,4061,4061,4062,4063,4064,4064,4065,4066,4066,4067,4068,4068,4069,4070,4070,4071,4072,4073,4073,4074,4075,4075,4076,4077,4077,4078,4079,4079,4080,4081,4081,4082,4083,4084,4084,4085,4086,4086,4087,4088,4088,4089,4090,4090,4091,4092,4093,4093,4094,4095,4095};

#include <SPI.h>
// SPI: SCK: PB5 - "Digital 13"
// SPI: MISO: PB4 - "Digital 12"
// SPI: MOSI:  PB3 - "Digital 11"
// SS: PB2 - "Digital 10"
const int chipSelectPin = 10;
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
void loop() {
  // read channel 0:
  auto data = readChannel(0);
  pitch_running_average = (alpha * pitch_running_average) >> 16;
  pitch_running_average += (oneMinusAlpha * data) >> 16;
  uint16_t pitchCV = pitch_running_average;
  uint16_t pitch = cvToPitch(pitchCV);
  uint16_t lin_pitch = pgm_read_word(&PITCH_LOOKUP_TABLE[pitch&4095]);
  uint16_t pitch_div_oct = (pitch >> 12);  
  if (pitch_div_oct >= octave_0_divider) {
     lin_pitch >> (pitch_div_oct - octave_0_divider);
     pitch_div_oct = 0;
  } else {
    pitch_div_oct = octave_0_divider - pitch_div_oct;
  }
  uint16_t divider = 1 << pitch_div_oct;

  auto mod_data = readChannel(1);
  mod_running_average = (alpha * mod_running_average) >> 16;
  mod_running_average += (oneMinusAlpha * mod_data) >> 16;
  auto divider_send = divider - 1;
  writeOsc(0, (mod_running_average >> 7) & 255);
  writeOsc(1, uint8_t((lin_pitch >> 8) & 255));  
  writeOsc(2, uint8_t(lin_pitch & 255));
  writeOsc(3, uint8_t((divider_send >> 8) & 255));  
  writeOsc(4, uint8_t(divider_send & 255));  
}

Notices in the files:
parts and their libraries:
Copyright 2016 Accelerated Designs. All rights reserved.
